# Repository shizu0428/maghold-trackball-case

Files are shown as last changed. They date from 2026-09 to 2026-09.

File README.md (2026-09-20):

# maghold-trackball-case

自作キーボードに組み込むための **磁気保持式トラックボールケース**（3Dプリント用モデルデータ）です。

トラックボール自体の磁性と、ケース底部に埋め込む磁石との引力を利用してボールを保持・固定します。ボールの脱落防止用の覆い（外枠・天面）がない構造のため、小径ボールでも指の接触範囲（操作エリア）を広く確保できるのが大きな特徴です。
<video src="https://github.com/user-attachments/assets/9145ee82-7418-4fc4-b364-56db967b2aee" autoplay loop muted playsinline width="100%"></video>

---

## 💡 特徴

- **広い操作エリア**  
  ボールを覆う外枠が存在しないため、指とボールの接触範囲を広く確保できます。比較的小さなトラックボールでも快適にカーソル操作が可能です。
- **柔軟なマウント対応**  
  キースイッチ穴（14×14mm）への装着や、torabo-tsuki LP等へのマウントに対応しています。  
- **操作性と持ち運びやすさの両立**  
  ボールを取り付けて使用する際には、ある程度の高さが出て指で操作しやすくなります。  
  一方、ボールを外して持ち運ぶ際にはケース自体の高さが抑えられるため、周囲のキートップと同程度になり移動時にかさばりません。  
  （※取り外したトラックボールはポーチの隙間やポケットなどに入れて持ち運んでください）


---

## ⚠️ 注意点（構造上の留意事項）

- **衝撃によるボールの脱落**  
ボールの操作性を重視し、静止状態で逆さにしても落ちない最低限の引力（磁力）で保持しているため、衝撃を受けると簡単にはずれてしまいます。
持ち運び時や使用時の取り扱いにご注意ください。
- **操作感への影響とベアリングの推奨**  
  磁石との引力が働く構造上、ボール操作時にやや重さを感じることがあります。  
  スムーズな操作感を得るため、高品質なベアリング（ミネベアミツミ製など）の使用を強くおすすめします。

---

## 📐 バリエーション・モデル一覧

用途や搭載するキーボードに応じて、複数のモデル（寸法・取り付け方式）を展開しています。  

### 14mmトラックボール用(1Uサイズ)
- **17mm狭ピッチ対応版（スイッチ穴マウント）**
👉 [データ](./14mm-case_17x17/)
  - キーピッチ17mm（狭ピッチ）の自作キーボード等に適した設計です。
  - ロープロファイルスイッチ穴（14×14×2.2mm）に直接取り付けます。
  - センサーの配置：ボール直下に水平
  - 人差し指での操作を想定していますが、サムクラスタに配置しても使用可能です。
  


- **サムクラスタ配置版（スイッチ穴マウント）**（準備中）
  - サムクラスタ配置に最適化させたバージョン（センサー配置斜め45°）を作成予定です。ケースのサイズは17mm狭ピッチ版よりもやや大きくなります。

### 19mmトラックボール用
サムクラスタの右端や，マイコン下の配置を想定しています。
ケースが1U(17x17mm)よりも大きく，周囲にスペースが必要です。寸法をご確認ください。




- **トッププレートマウント用**
👉 [データ](./19mm-case/)
  - 19mm径のトラックボールをサムクラスタでの使用に適した設計です。
  - ロープロファイルスイッチ穴（14×14×2.2mm）に直接取り付けます。

- **torabo-tsuki LP ボトムプレートマウント用**
👉 [データ](./19mm-case_torabotsukiLP/)
  - torabo-tsuki LPのボトムプレートへ直接マウントするタイプです。
  - torabo-tsuki LPに付属しているM2ネジ2本を使用して，ボトムプレートに固定してください。

---

## 🔮 対応トラックボール（磁性のあるもの）

本ケースは、ケース側の磁石とトラックボール自体の磁力で保持する構造のため、**磁性（磁石に引き寄せられる性質）を持つトラックボール**が必要です。当方で磁性を確認済みの購入先は以下の通りです。

- **14mm トラックボール**  
  👉 [beekeeb.jp](https://shop.beekeeb.jp/products/14mm-trackball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)  
※2026年9月現在，購入ができない状況です。

- **19mm トラックボール**  
  👉 [beekeeb](https://shop.beekeeb.com/products/19mm-trackball)  
  ※beekeebの19mmボールについては、**18gタイプ（オレンジレッド、チェリーレッド、ダークグレー）でのみ**磁性があることを確認済みです。

  👉 [ゆ〜キーショップ (BOOTH)](https://yukeyshop.booth.pm/items/8697940)

> ⚠️ **注意点**  
> 各トラックボールに磁性があることは販売元公式の公称仕様ではありません。当方で入手した個体においては磁性があり、本ケースで問題なく保持・操作できることを確認済みですが、ロットや仕様変更等により動作が異なる可能性がある点をご了承ください。

---

## 🛠 動作対応センサー

本ケースは、せきごん氏設計の下記モジュールに対応しています。

- **14mmマウスセンサーモジュール**（のぎけす屋 / BOOTH）  
  👉 [https://nogikes.booth.pm/items/6520217](https://nogikes.booth.pm/items/6520217)

---

## 🔧 ビルドガイド

### 1. 準備物
- 本ケースデータ（3Dプリント品）
- 対応トラックボール（14mm / 磁性あり）
- **磁石（5 × 10 × 1 mm）× 1個(19mm球の場合は2個)**  
  👉 [Amazon 購入ページ例](https://www.amazon.co.jp/dp/B0BQ65CP2V?ref=ppx_yo2ov_dt_b_fed_asin_title&th=1)
- **ベアリング（外径4 × 内径1.5 × 厚み2 mm）× 3個** （※ミネベアミツミ製などの高品質ベアリングを推奨）
- M1.4ねじ× 3本
- M2ねじ× 2本 (torabo-tsuki LP用の場合)
- 14mmマウスセンサーモジュール
- FPC/FFC フレキシブルケーブル（0.5mmピッチ / 6P）

### 2. 組み立て手順
1. **ケースのプリント**  
   本リポジトリのケースデータを、お手持ちの3Dプリンターや外注サービス（JLC3DPなど）で造形します。
2. **磁石の取り付け**  
   ケースの所定位置に磁石（5×10×1mm）を挿入・固定します。  
   14mm球の場合は磁石は1個，19mm球の場合は磁石を2個重ねて挿入します。  
   
   

3. **ベアリングの固定**  
   ベアリング（4×1.5×2mm）をM1.4ねじで固定します（計3箇所）。
4. **センサーの組み込み**  
   14mmマウスセンサーモジュールをケースに取り付けます。  
   
5. **キーボードへの固定**  
   組み立てたトラックボールケースを、キーボードのトッププレート（スイッチ穴）に差し込みます。
   torabo-tsuki LP用の場合は，M2ネジ2本を使用してボトムプレートに取り付けます。
7. **ケーブルの配線・接続**  
   フレキシブルケーブル（0.5mmピッチ / 6P）をキーボード本体基板と接続します。  
   ※フレキシブルケーブルは、スイッチソケット用の中央穴を通して配線可能です。  
   

---

## 🚨 免責事項 / Disclaimer

本リポジトリで提供しているモデルデータ（3Dプリント用データ）および関連情報を用いて作成・製造された物品（トラックボールケース本体や組込み後のキーボード等）に関して発生した、いかなる事故・怪我・端末の不具合・損害等について、制作者（@shizu0428）は一切の責任を負いません。すべて自己責任において制作およびご使用を行ってください。

---

## 📜 ライセンス / License

本リポジトリのモデルデータは [CC BY-NC 4.0](http://creativecommons.org/licenses/by-nc/4.0/) の下で公開されています。
- **個人・非営利目的:** クレジット表示の上、自由にご利用・改変いただけます。
- **商用利用:** 原則禁止ですが、個別に相談を受け付けております。詳細は [LICENSE](./LICENSE) ファイルをご確認ください。

### お問い合わせ先
- GitHub: [@shizu0428](https://github.com/shizu0428)
- X (旧Twitter): [@shizu0428](https://x.com/shizu0428)

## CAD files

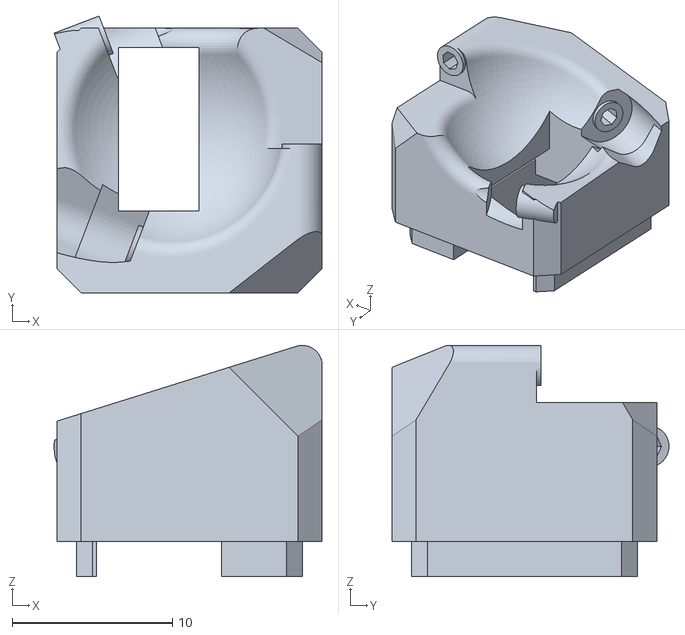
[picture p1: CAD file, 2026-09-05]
14mm-case_17x17/14mm_maghold-TBcase_mirror_v1.stl
16.7 x 17.3 x 14.4

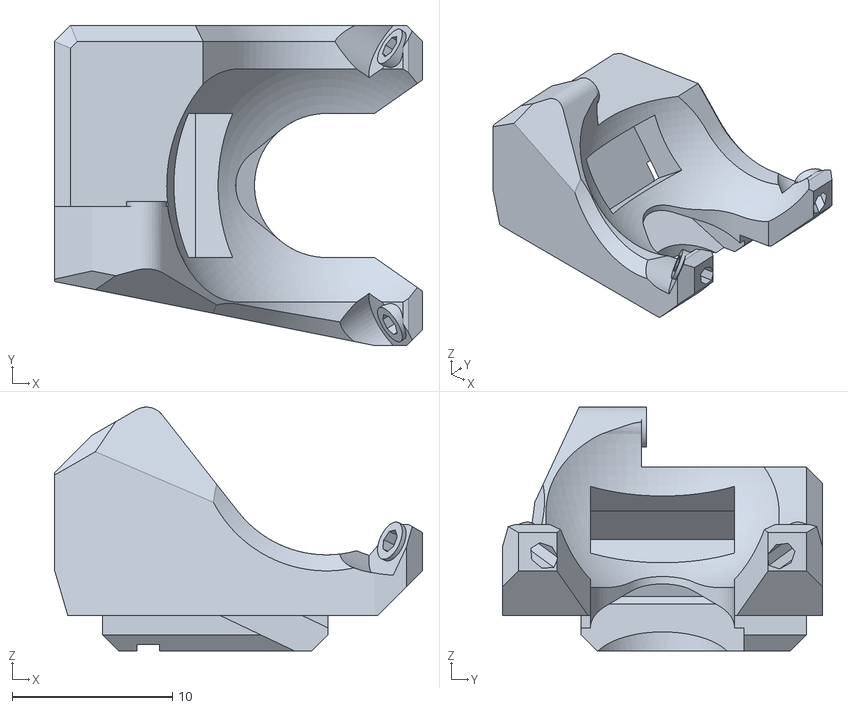
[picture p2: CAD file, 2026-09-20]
19mm-case/19mm_maghold-TBcase_mirror_v2.stl
23.0 x 20.0 x 15.2

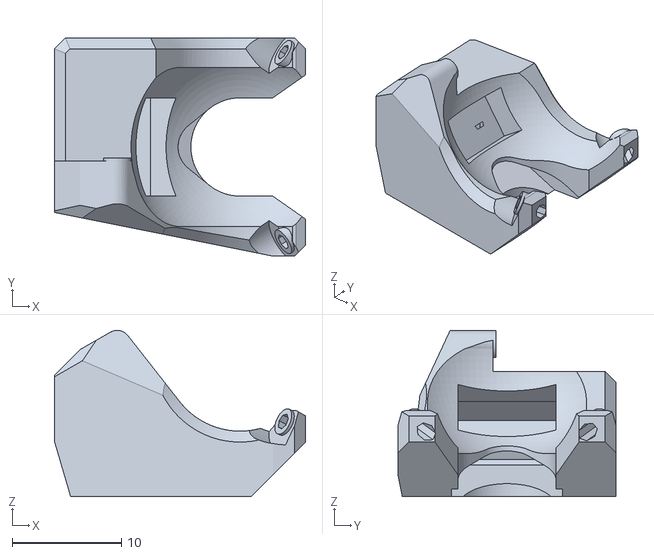
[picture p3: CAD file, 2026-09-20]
19mm-case_torabotsukiLP/19mm_maghold-TBcase_torabo-tsukiLP_mirror_v2.stl
23.0 x 20.0 x 15.2

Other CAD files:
14mm-case_17x17/14mm_maghold-TBcase_v1.stl
19mm-case/19mm_maghold-TBcase_v2.stl
19mm-case_torabotsukiLP/19mm_maghold-TBcase_torabo-tsukiLP_v2.stl

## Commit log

2026-09-05 Update README with 14mm trackball specifications
    Add details for 14mm trackball models and their configurations.
2026-09-05 Revise 19mm trackball information in README
    Updated the 19mm trackball section with new links and details.
2026-09-20 Revise title for 19mm trackball section
    Updated section title for clarity regarding trackball usage.
2026-09-20 Revise build guide for clarity and accuracy
    Updated the build guide section with corrected item names and added details for screws.
